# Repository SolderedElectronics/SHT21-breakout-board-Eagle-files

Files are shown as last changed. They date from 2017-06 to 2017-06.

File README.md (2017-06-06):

# SHT21 temperature & humidity sensor breakout Eagle files
## Image
sht21 image
[SHT21 breakout(101378)][board]

## Description and details
SHT21 became icon of industrial temperature & humidity sensor. Device provides calibratied, linearized signal in digital I2C format. Sensor is made in Switzerland and offers great preformances with proven stability and durability. 

## Repository content
This repo contains Cadsoft Eagle .sch and .brd files for BTR board. It also contains schematic in .pdf created from .sch Eagle file. 
Files have been arranged into folders for navigating between different versions of board. 
Tip: layer 200 shows top silkscreen and layer 208 should be bottom silkscreen. tParts and bParts are not used.

## Docs
- [SHT21 breakout product page][board]
- [SHT21 Arduino library][library]

## Board versions
- v1.0 - inital version

## License info
This product is open-source. Yay!
For any tech questions, contact us at techsupport@e-radionica.com
If you find an Issue, please open one at GitHub. If you can improve our product, fork it!

e-r.io Team.

[board]: https://e-radionica.com/en/sht21-humidity-and-temperature-sensor.html
[library]: https://github.com/e-radionicacom/SHT21-Arduino-Library

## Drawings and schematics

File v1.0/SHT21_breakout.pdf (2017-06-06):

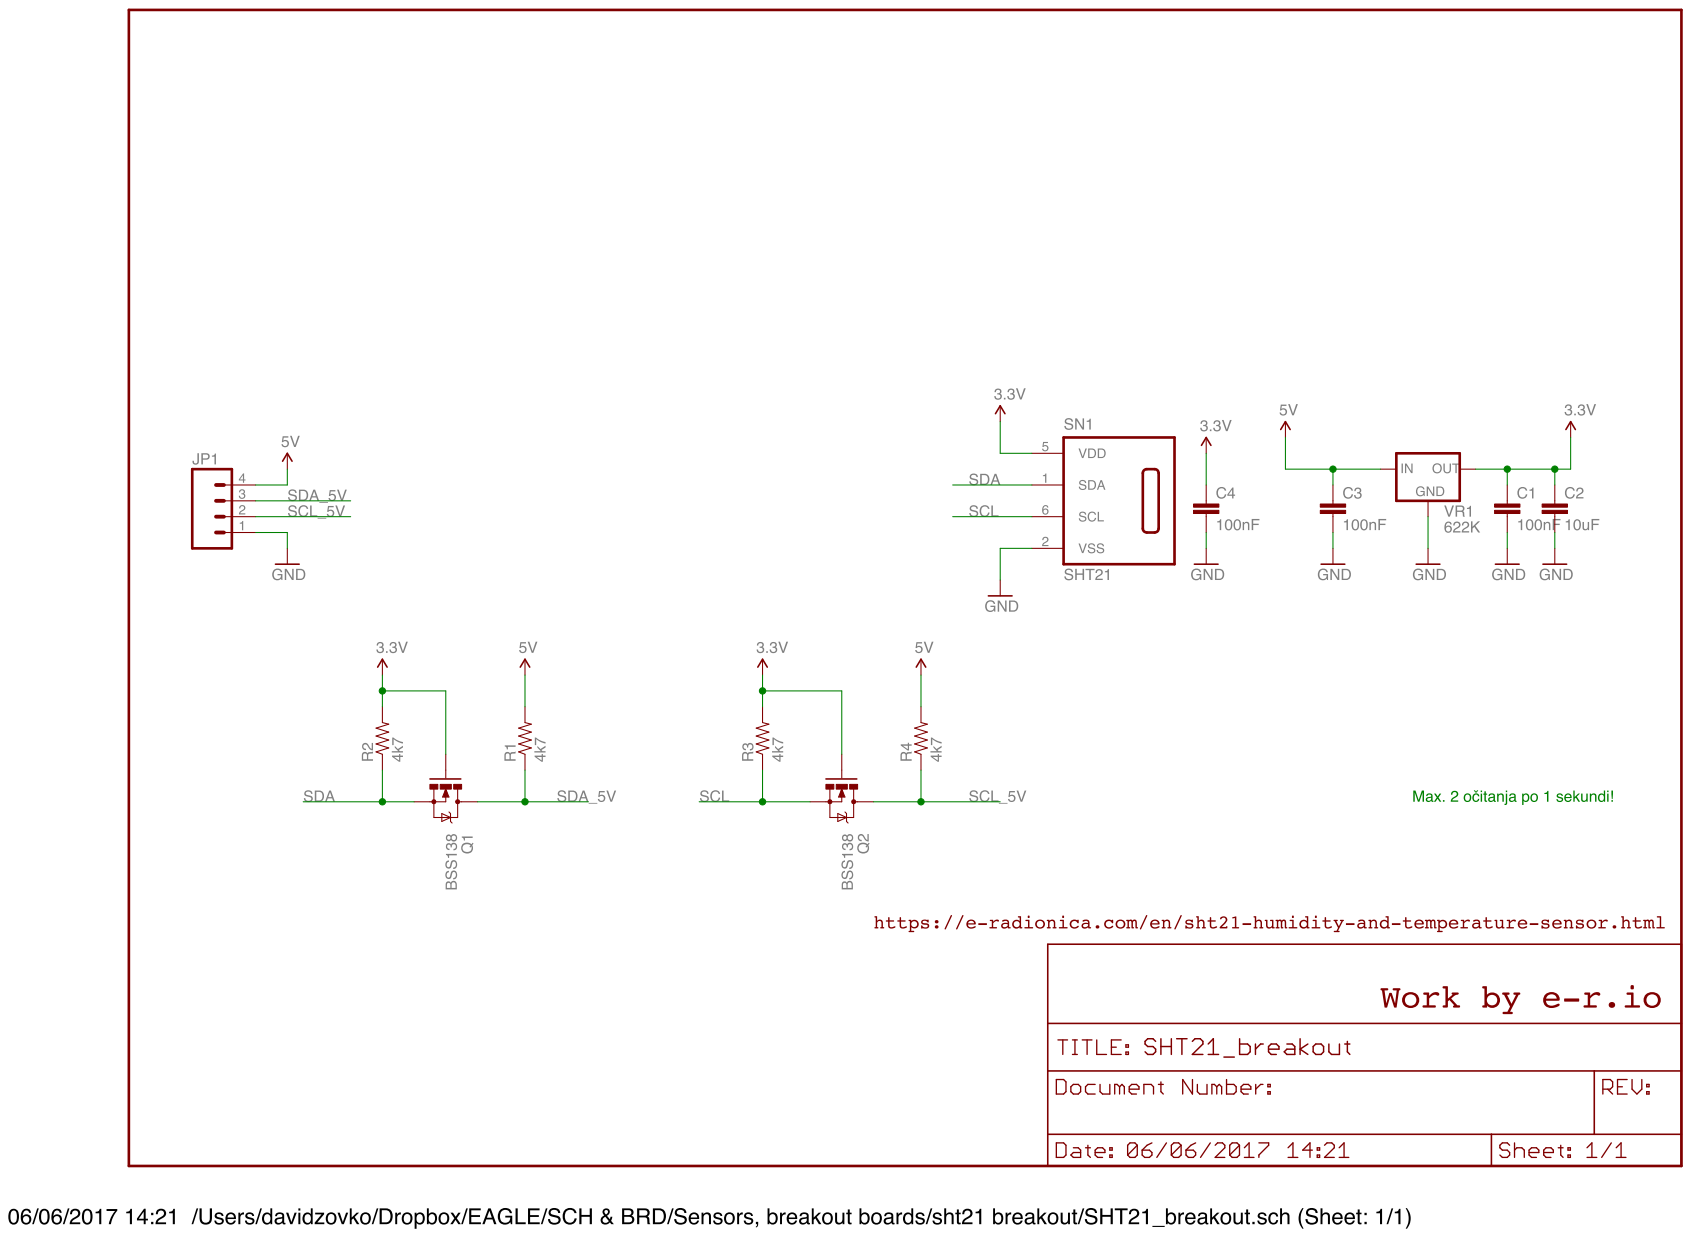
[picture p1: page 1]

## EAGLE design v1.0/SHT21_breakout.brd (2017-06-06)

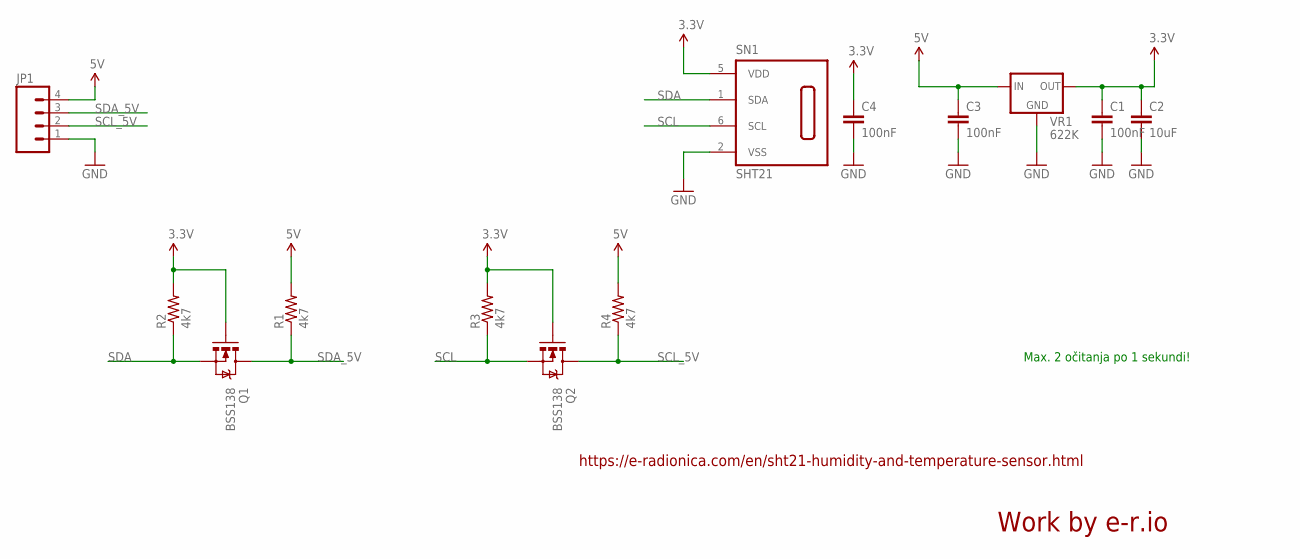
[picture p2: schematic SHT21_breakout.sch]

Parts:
C1, C3, C4: 100nF; 0603-CAP
C2: 10uF; 1206
JP1: M04PTH; 1X04
Q1, Q2: BSS138; SOT23-3
R1, R2, R3, R4: 4k7; 0603-RES
SN1: SHT21; DFN6/SHT
VR1: 622K; 662K

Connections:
3.3V: C1.1, C2.1, C4.1, Q1.1 (G), Q2.1 (G), R2.2, R3.2, SN1.5 (VDD), VR1.OUT
5V: C3.1, JP1.4, R1.2, R4.2, VR1.IN
GND: C1.2, C2.2, C3.2, C4.2, JP1.1, SN1.2 (VSS), VR1.GND
SCL: Q2.2 (S), R3.1, SN1.6 (SCL)
SCL_5V: JP1.2, Q2.3 (D), R4.1
SDA: Q1.2 (S), R2.1, SN1.1 (SDA)
SDA_5V: JP1.3, Q1.3 (D), R1.1

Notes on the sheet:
Max. 2 očitanja po 1 sekundi!
https://e-radionica.com/en/sht21-humidity-and-temperature-sensor.html
Work by e-r.io

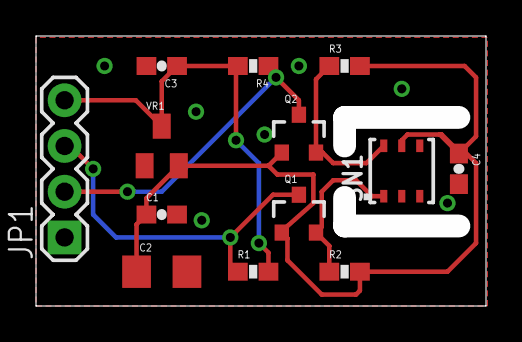
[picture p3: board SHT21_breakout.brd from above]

Board: 2 copper layers, 25.0 x 15.0 mm, 17 parts (0 on the bottom side), 7 nets.

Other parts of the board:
U$1: LUDI_LOGO_BACK
U$6: NOVI_LOGO-4MM
U$7: OSH3MM
U$8: E-RADIONICA.COM_MADE_IN_BACK!

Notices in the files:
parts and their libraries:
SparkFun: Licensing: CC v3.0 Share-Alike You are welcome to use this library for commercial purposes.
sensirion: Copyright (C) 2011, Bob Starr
